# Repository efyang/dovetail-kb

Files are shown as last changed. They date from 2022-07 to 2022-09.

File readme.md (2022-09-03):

# Dovetail Keyboard

Uses a modified version of ergogen that supports placing arbitrary library parts.

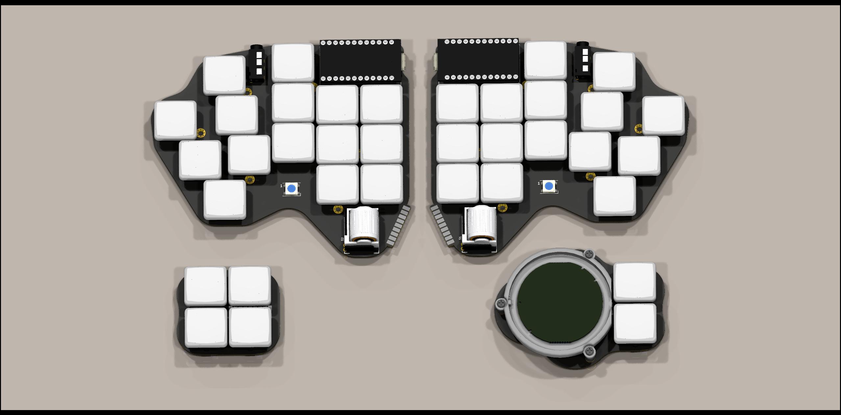
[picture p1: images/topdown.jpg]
Top Down

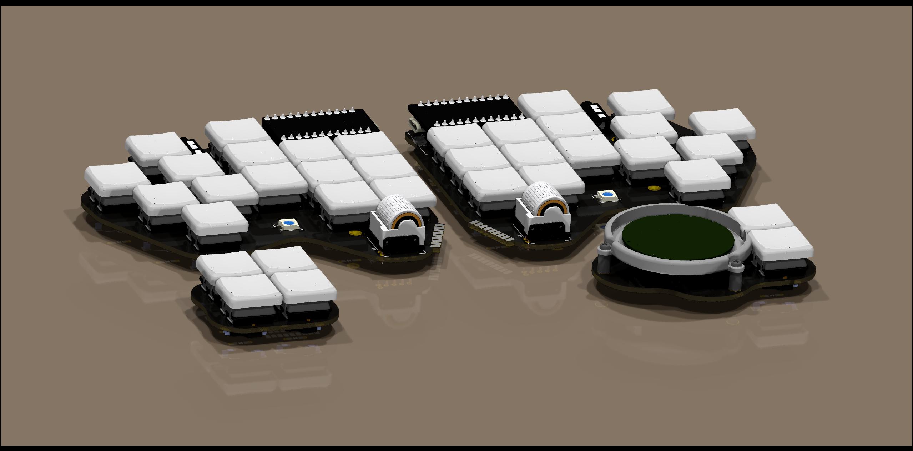
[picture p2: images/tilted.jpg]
Tilted

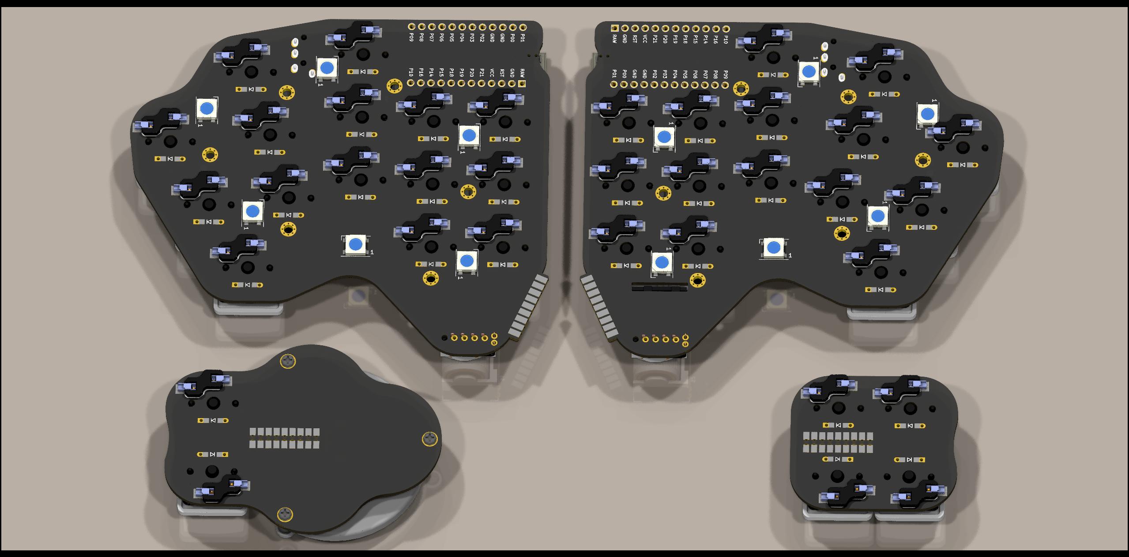
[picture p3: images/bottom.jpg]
Bottom


### FreeCAD Pics (some parts didn't survive the conversion process)

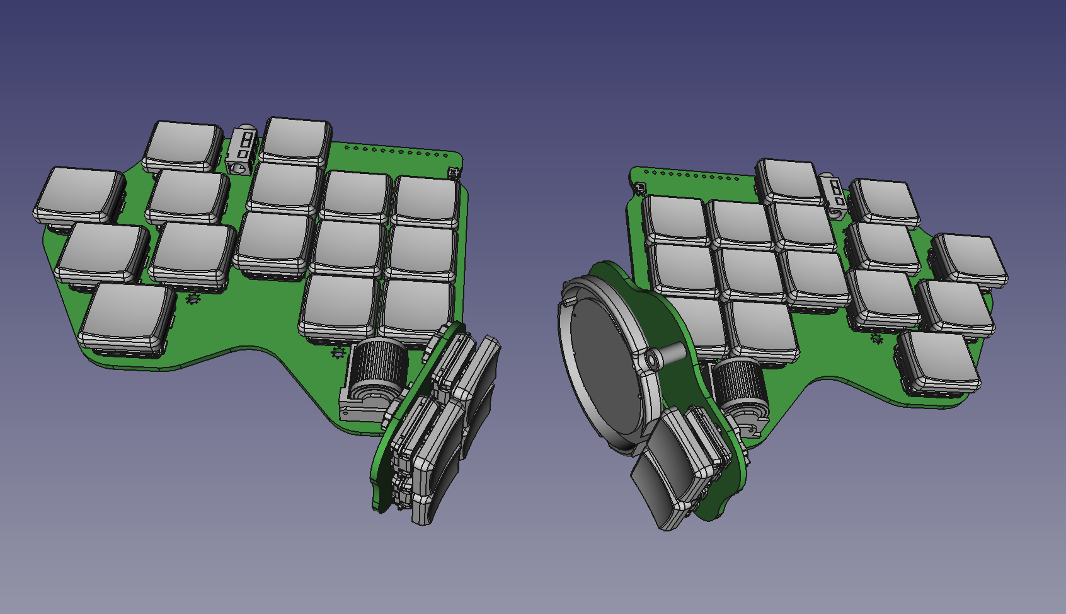
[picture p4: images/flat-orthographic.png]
Flat Orthographic

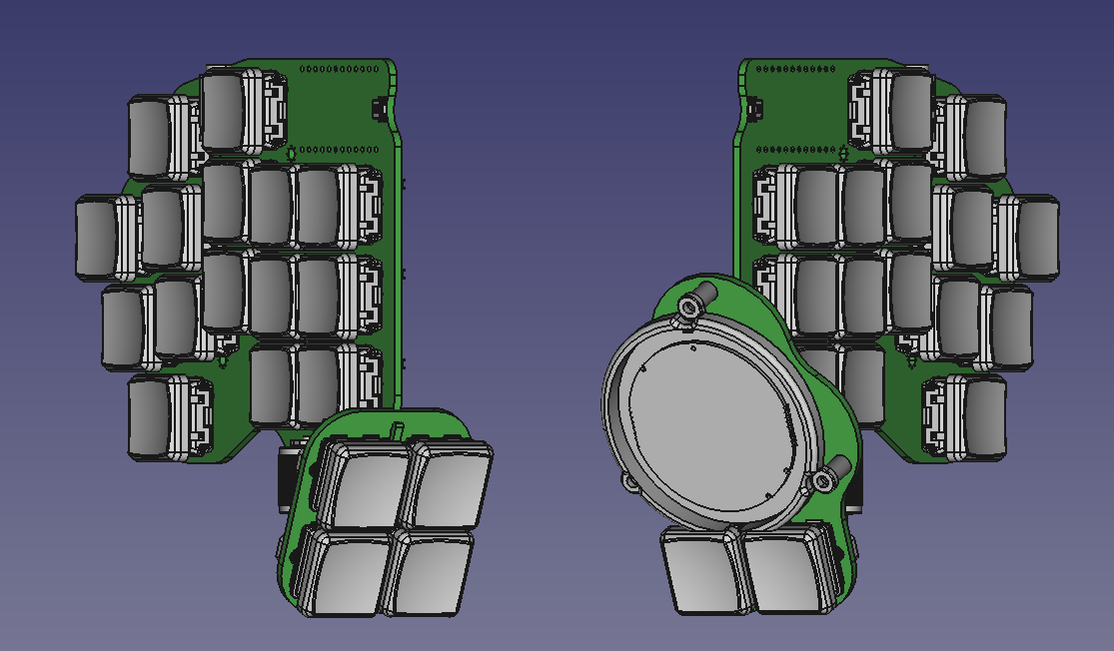
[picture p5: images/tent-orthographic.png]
Tented Orthographic

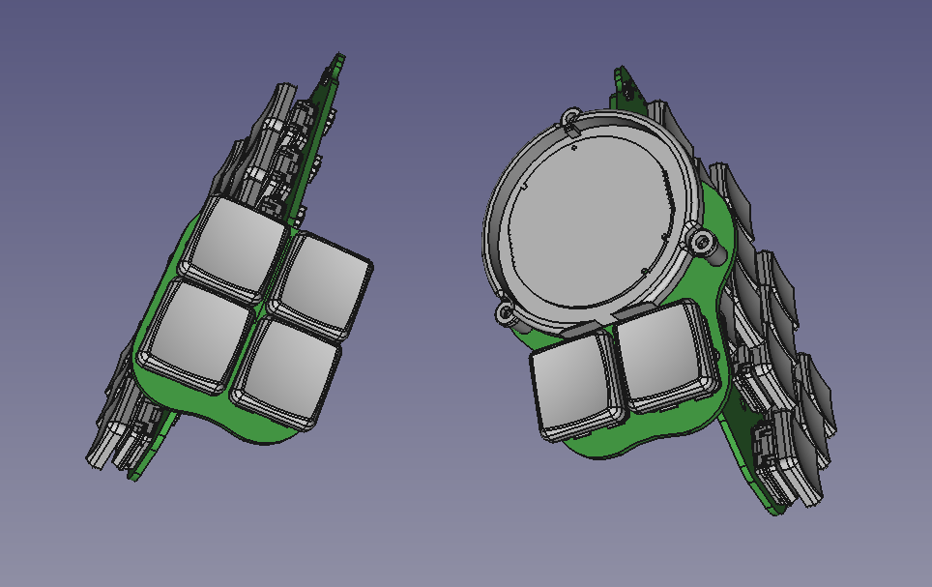
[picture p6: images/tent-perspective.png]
Tented Perspective


## Features

-   underglow
-   trackpad (tm035035-2024-003)
-   solder-on 90-degree thumb clusters
-   choc spacing
-   36 keys

To update using ergogen:

-   `node ergogen/src/cli.js ergogen.yaml -o .`
-   Open pcb in pcbnew
-   Tools -> Update Footprints from Library
-   Check all "Update Options"
-   Update

## Parts list

| Qty | Part | Info | Link(s) | |
| --- | --- | --- | --- | --- |
| 2 | KB2040 | QMK compatible pro-micro footprint. Currently must have QMK for trackpad, recommmended RP2040 | https://www.adafruit.com/product/5302 | |
| 2 | PJ-320A Jack | | https://www.aliexpress.com/item/2251832181971069.html | |
| 36  | Kailh Choc Hotswap Sockets | | https://www.aliexpress.com/item/3256803389452947.html | |
| 3 | M2 Standoffs | Trying M2x7 | https://www.aliexpress.com/item/2251832782516182.html | |
| idk can't count | M2 Screws | | | |
| 1 | FPC Cable | 0.5mm pitch, 12pin, same side (but probably should cut and strip yourself anyways) | https://www.aliexpress.com/item/3256801417741263.html | |
| 1 | FPC Connector | 12P, 0.5mm pitch | https://www.aliexpress.com/item/2261800162045502.html | |
| 4 | MCU Sockets (optional) | I like these ones - PH3.5, use them with regular headers | https://www.aliexpress.com/item/2251832713321083.html | |
| 2 | Scroll Wheel | | https://www.aliexpress.com/item/2251832804635444.html | |
| 14  | WS2812b 5050 | | https://www.aliexpress.com/item/3256802466699315.html | |
| 1 | TM035035-2024-003 Trackpad | Cirque Glide Trackpad with overlay | https://www.mouser.com/ProductDetail/355-TM0350352024-003 | |
| 2 | EVQ-P7C01P Reset Switch | I wanted to be fancy lol | https://www.mouser.com/ProductDetail/667-EVQP7C01P | |
| 1 | Trackpad holder part | Probably want 2 just in case | [In repo](Models/trackpad-holder-Fusion.stl) | |
| 1 | 1 of each PCB minimum | left-main, right-main, left-thumb, right-thumb (you could actually interchange the thumbs) | [In repo](gerbers) | |
| 2 | Plates | Untested | [In repo](outlines/cutout_with_holes.dxf) | |
| 12 | M2 standoffs (5mm) | Untested | https://www.aliexpress.com/item/2251832782591461.html | |
| 2  | 1/4in lock nut | Untested | https://www.aliexpress.com/item/3256802483856268.html | |
| 2  | Camera swivel thingy | Untested | https://www.aliexpress.com/item/3256803400603212.html | |
| 2  | Magnetic Base | Untested | https://www.aliexpress.com/item/3256803496352836.html | |
| 2  | Palm LED Diffuser | Untested | [In repo](outlines/palm_led_diffuser_final.dxf) | |
| 2  | Palm LED Diffuser Spacer | Untested | [In repo](outlines/palm_led_diffuser_spacer.dxf) | |
| 36  | Diodes | | | |
| 1 | Case (optional) | | https://www.aliexpress.com/item/3256803532895347.html | |

## Notes

-   Designed for 3.3v power/logic (kb2040)
    -   if you want to use 5v then you have to desolder more on the trackpad pcb
-   Rectangular size (at most): ~ 14cmx11cmx5.5cm

## Inspo/Useful Links
- https://www.reddit.com/r/ErgoMechKeyboards/comments/uq2yyq/kyria_with_cirque_circle_trackpad/
- https://github.com/macroxue/keyboard-tenting
- https://www.reddit.com/r/PeripheralDesign/comments/uk9l94/trackball_emulation_on_cirque_glidepoint_circle/
- https://www.cirque.com/message-board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
- https://github.com/dkao/qmk_firmware/commits/cirque_trackpad_features
- https://www.thingiverse.com/thing:5385829/files
- https://github.com/Bastardkb/dilemma

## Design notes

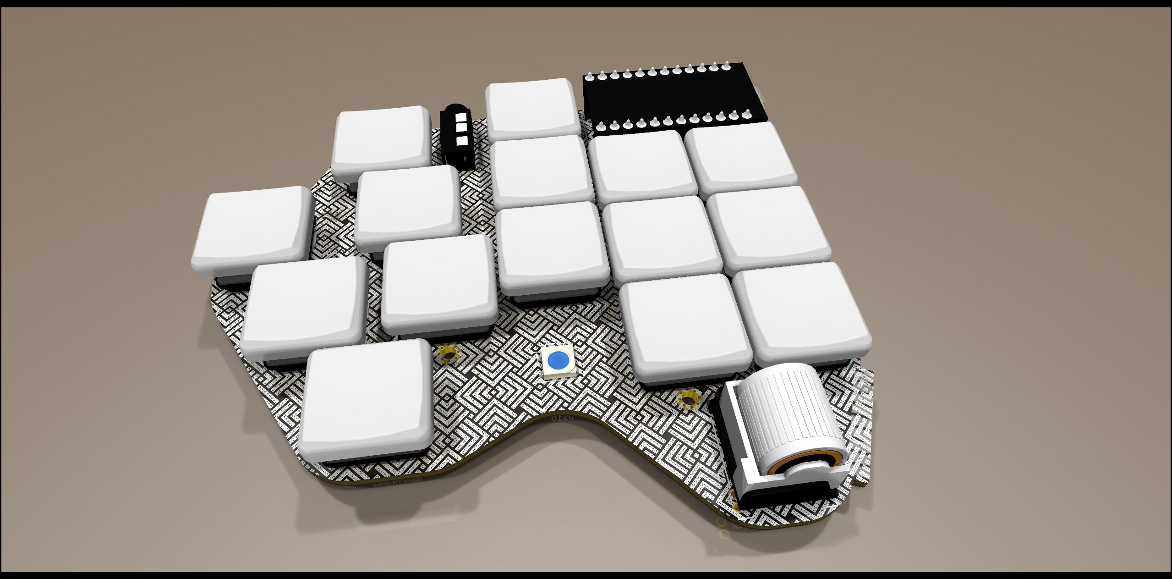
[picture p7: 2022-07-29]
images/patterned.jpg

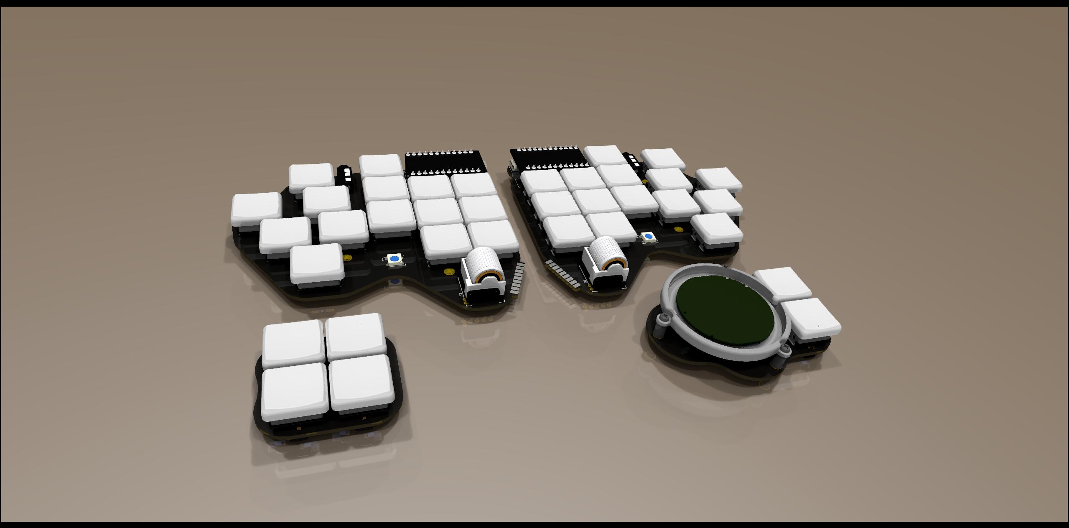
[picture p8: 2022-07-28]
images/tilted2.jpg

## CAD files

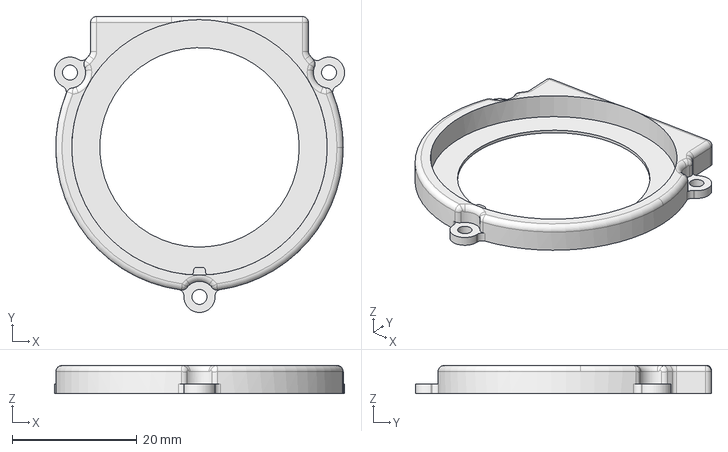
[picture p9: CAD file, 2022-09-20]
Models/trackpad-holder.FCStd
46.6 x 47.5 x 4.50 mm

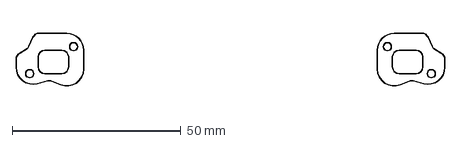
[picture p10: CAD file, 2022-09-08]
outlines/palm_led_diffuser_spacer.dxf
127.0 x 15.9 mm

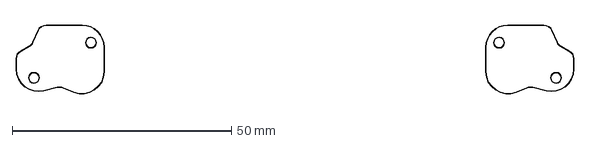
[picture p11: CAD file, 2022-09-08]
outlines/palm_led_diffuser_final.dxf
127.0 x 15.9 mm

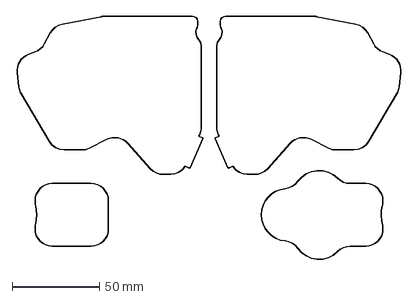
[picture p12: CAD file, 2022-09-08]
outlines/cutout_final.dxf
220.3 x 139.3 mm

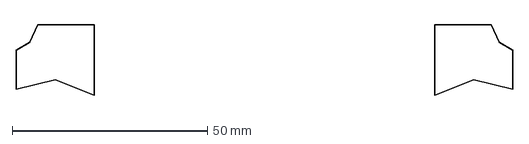
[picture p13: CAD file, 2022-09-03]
outlines/palm_led_diffuser_outline.dxf
127.0 x 18.0 mm

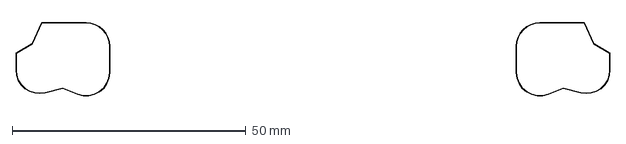
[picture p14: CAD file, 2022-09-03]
outlines/palm_led_diffuser_stage0.dxf
127.0 x 15.9 mm

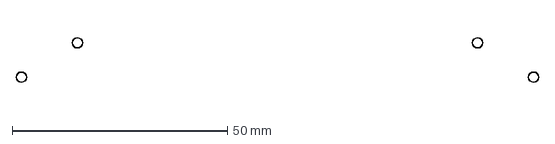
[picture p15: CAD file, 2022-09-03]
outlines/palm_led_diffuser_holes.dxf
121.4 x 10.4 mm

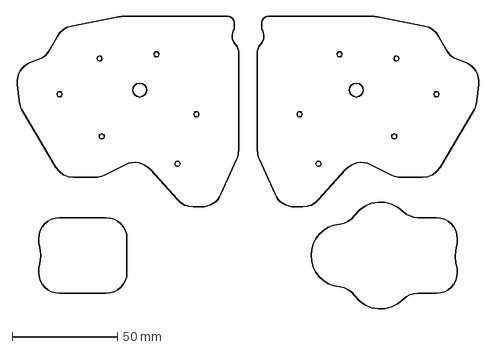
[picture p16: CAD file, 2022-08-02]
outlines/cutout_with_holes.dxf
220.3 x 139.3 mm

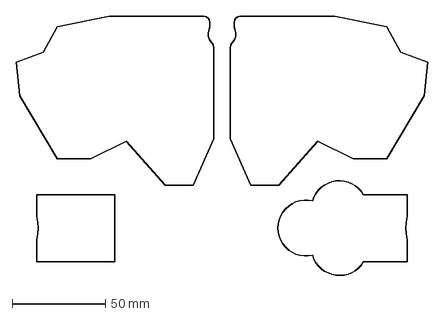
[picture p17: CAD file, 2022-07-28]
outlines/cutout_all.dxf
221.0 x 139.6 mm

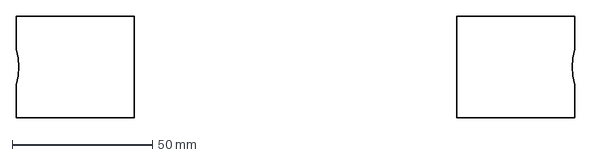
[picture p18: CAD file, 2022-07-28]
outlines/thumbrect_stage1.dxf
199.0 x 36.0 mm

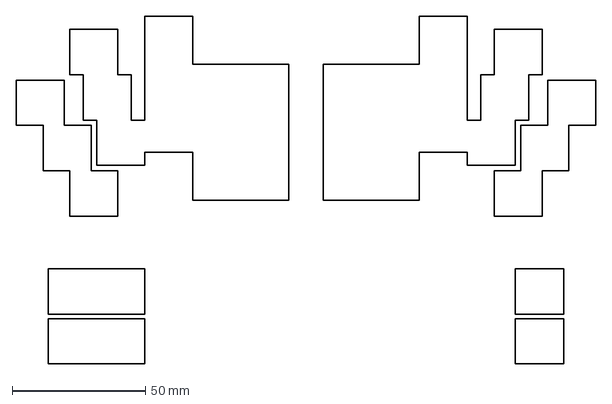
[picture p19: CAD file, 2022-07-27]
outlines/raw.dxf
217.0 x 130.4 mm

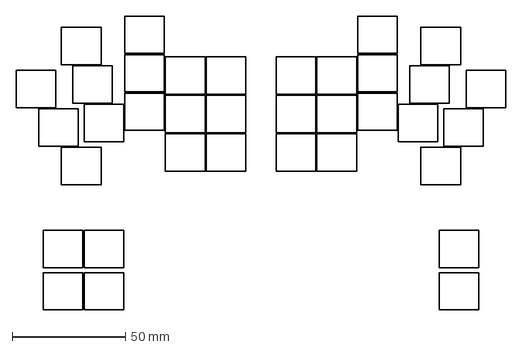
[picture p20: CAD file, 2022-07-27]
outlines/keycap_outlines.dxf
216.5 x 129.9 mm

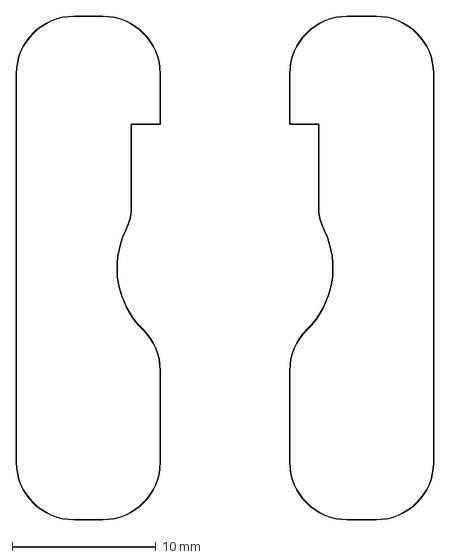
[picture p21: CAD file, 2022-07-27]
outlines/reset_nub_smooth1.dxf
29.0 x 35.0 mm

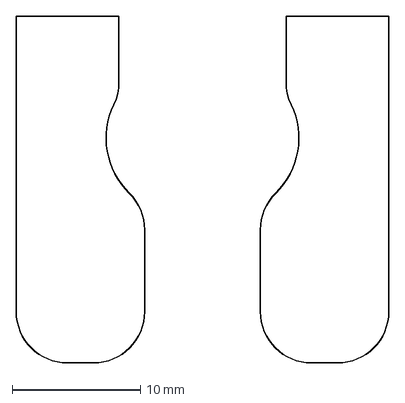
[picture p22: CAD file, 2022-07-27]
outlines/reset_nub.dxf
29.0 x 27.0 mm

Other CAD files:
Models/trackpad-holder-Fusion.step
outlines/reset_nub_stage1.dxf
Models/trackpad-holder-Fusion.stl

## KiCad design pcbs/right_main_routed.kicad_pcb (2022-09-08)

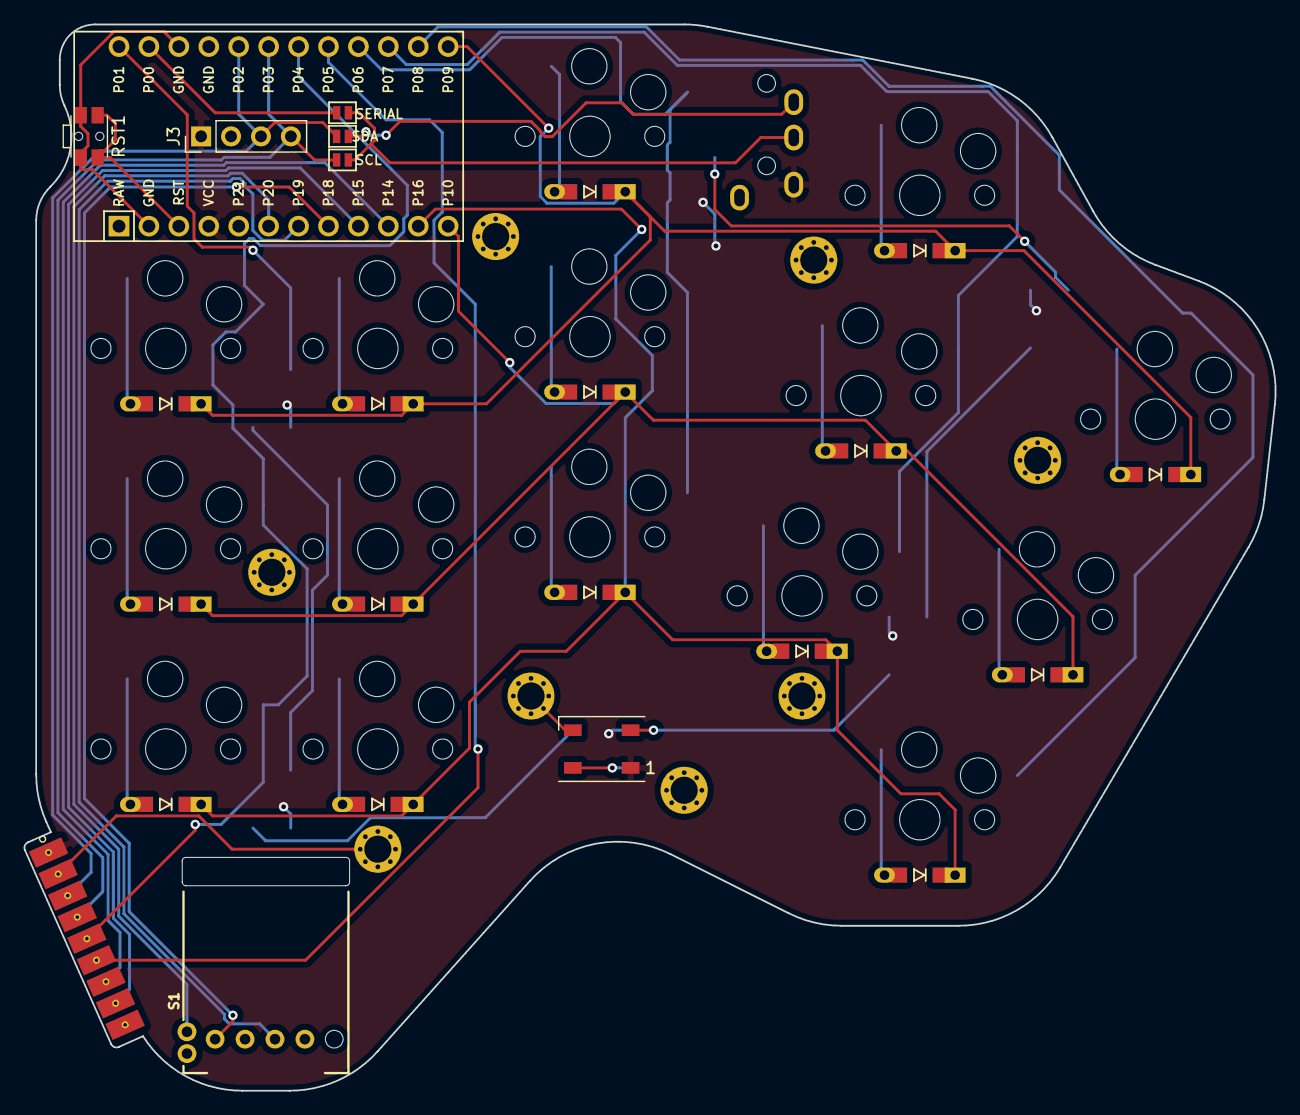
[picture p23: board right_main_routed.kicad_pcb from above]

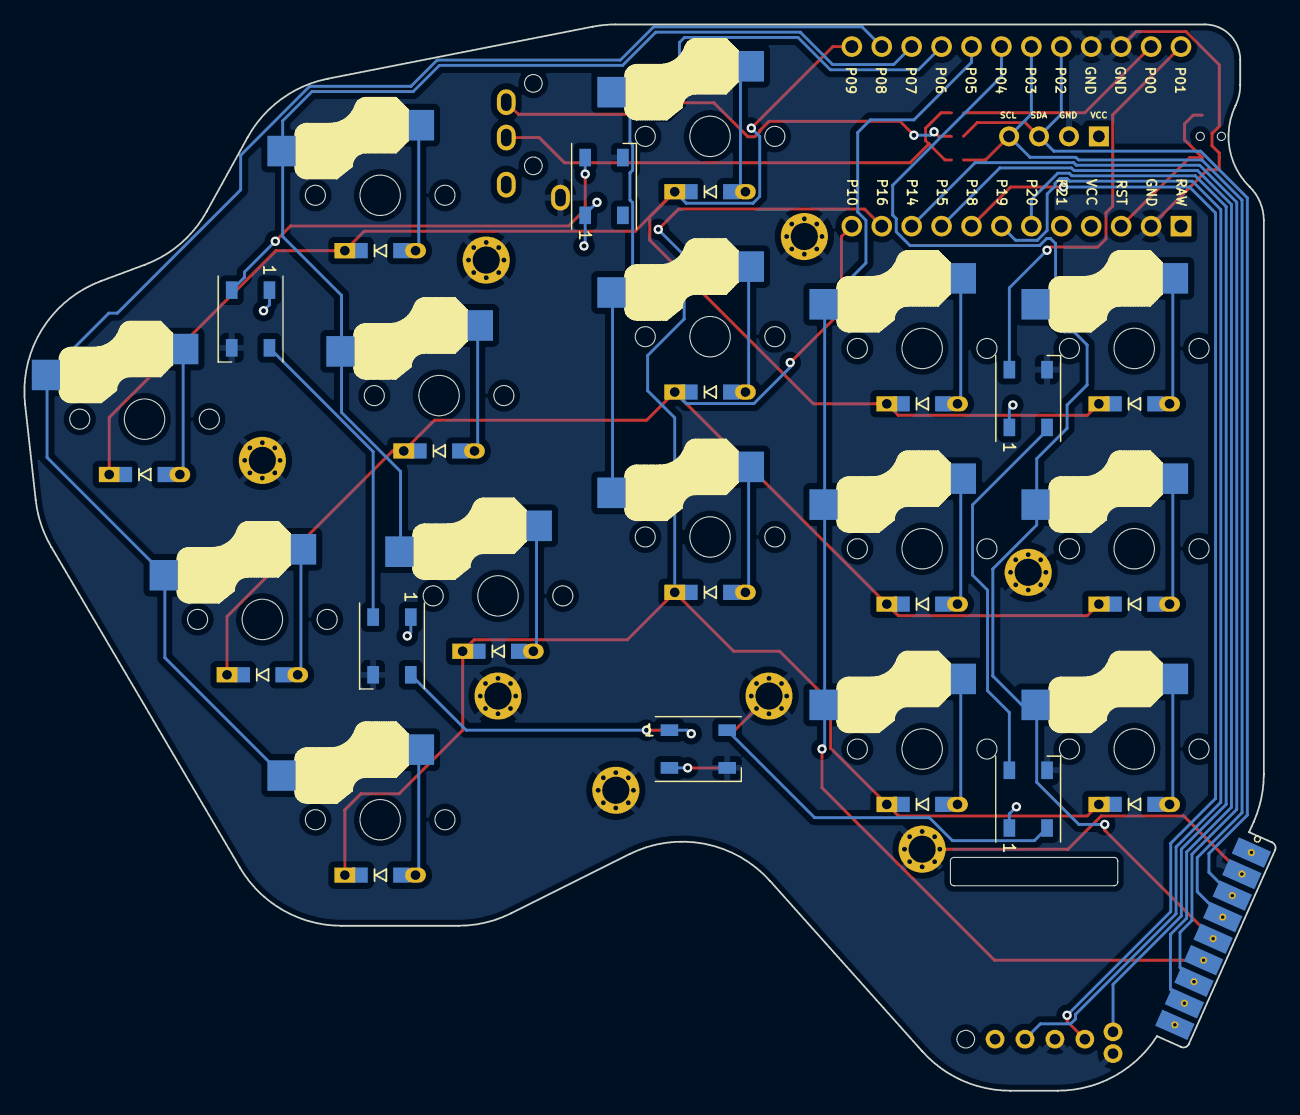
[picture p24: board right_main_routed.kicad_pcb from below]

Board: 2 copper layers, 106.2 x 90.5 mm, 54 parts (6 on the bottom side), 43 nets.

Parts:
D1, D2, D3, D4, D5, D6, D7, D8, D9, D10, D11, D12, D13, D14, D15: Diode; D3_TH_SMD_v2
DS1, DS2, DS3, DS4, DS5, DS6, DS7: WS2812b; LED_WS2812B_PLCC4_5.0x5.0mm_P3.2mm
H1, H3, H5, H7, H9, H11, H13, H15: M2; M2_HOLE_v3
J1: TRRS; TRRS-PJ-320A
J3: I2C Breakout; PinHeader_1x04_P2.54mm_Vertical
J5: SERIAL; Jumper
J6: SDA; Jumper
J7: SCL; Jumper
J14: Male 9pin; kb_90deg_connector_male_9pin
RST1: RST; SW_SPST_EVQP7C
S1: Scroll Wheel; EVQWGD001
SW1, SW2, SW3, SW4, SW5, SW6, SW7, SW8, SW9, SW10, SW11, SW12, SW13, SW14, SW15: Val**; PG1350
U1: Pro Micro Footprint; ProMicro

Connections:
C1: J14.5, SW1.2, SW2.2, SW3.2, U1.19
C2: J14.6, SW4.2, SW5.2, SW6.2, U1.20
C3: SW7.2, SW8.2, SW9.2, U1.21
C4: SW10.2, SW11.2, SW12.2, U1.22
C5: SW13.2, SW14.2, SW15.2, U1.23
GND: DS1.3, DS2.3, DS3.3, DS4.3, DS5.3, DS6.3, DS7.3, H1.1, H3.1, H5.1, H7.1, H9.1, H11.1, H13.1, H15.1, J1.1, J3.2, J14.2, RST1.2, S1.B, S1.S1, U1.2, U1.15, U1.16
R1: D3.1, D6.1, D9.1, D12.1, D15.1, U1.24
R2: D2.1, D5.1, D8.1, D11.1, D14.1, U1.12
R3: D1.1, D4.1, D7.1, D10.1, D13.1, U1.11
R4: J14.7, U1.10
R5: J14.8, U1.9
RGB: DS1.4, U1.13
RST: RST1.1, U1.3
SCL: J3.4, J7.1, J14.4, U1.18
SDA: J3.3, J6.1, J14.3, U1.17
SERIAL: J5.1, U1.14
TRRS3: J1.3, J5.2, J7.2
TRRS4: J1.4, J6.2
VCC: DS1.1, DS2.1, DS3.1, DS4.1, DS5.1, DS6.1, DS7.1, J1.2, J3.1, J14.1, U1.4
far_bottom: D1.2, SW1.1
far_home: D2.2, SW2.1
far_top: D3.2, SW3.1
index_bottom: D4.2, SW4.1
index_home: D5.2, SW5.1
index_top: D6.2, SW6.1
middle_bottom: D7.2, SW7.1
middle_home: D8.2, SW8.1
middle_top: D9.2, SW9.1
pinkie_bottom: D13.2, SW13.1
pinkie_home: D14.2, SW14.1
pinkie_top: D15.2, SW15.1
rgb_palm_out: DS4.2, DS5.4
rgb_ug1_out: DS1.2, DS2.4
rgb_ug2_out: DS2.2, DS3.4
rgb_ug3_out: DS3.2, DS4.4
rgb_ug4_out: DS5.2, DS6.4
rgb_ug5_out: DS6.2, DS7.4
ring_bottom: D10.2, SW10.1
ring_home: D11.2, SW11.1
ring_top: D12.2, SW12.1
scroll_r1: S1.A, U1.8
scroll_r2: S1.C, U1.7
scroll_switch: S1.S2, U1.6

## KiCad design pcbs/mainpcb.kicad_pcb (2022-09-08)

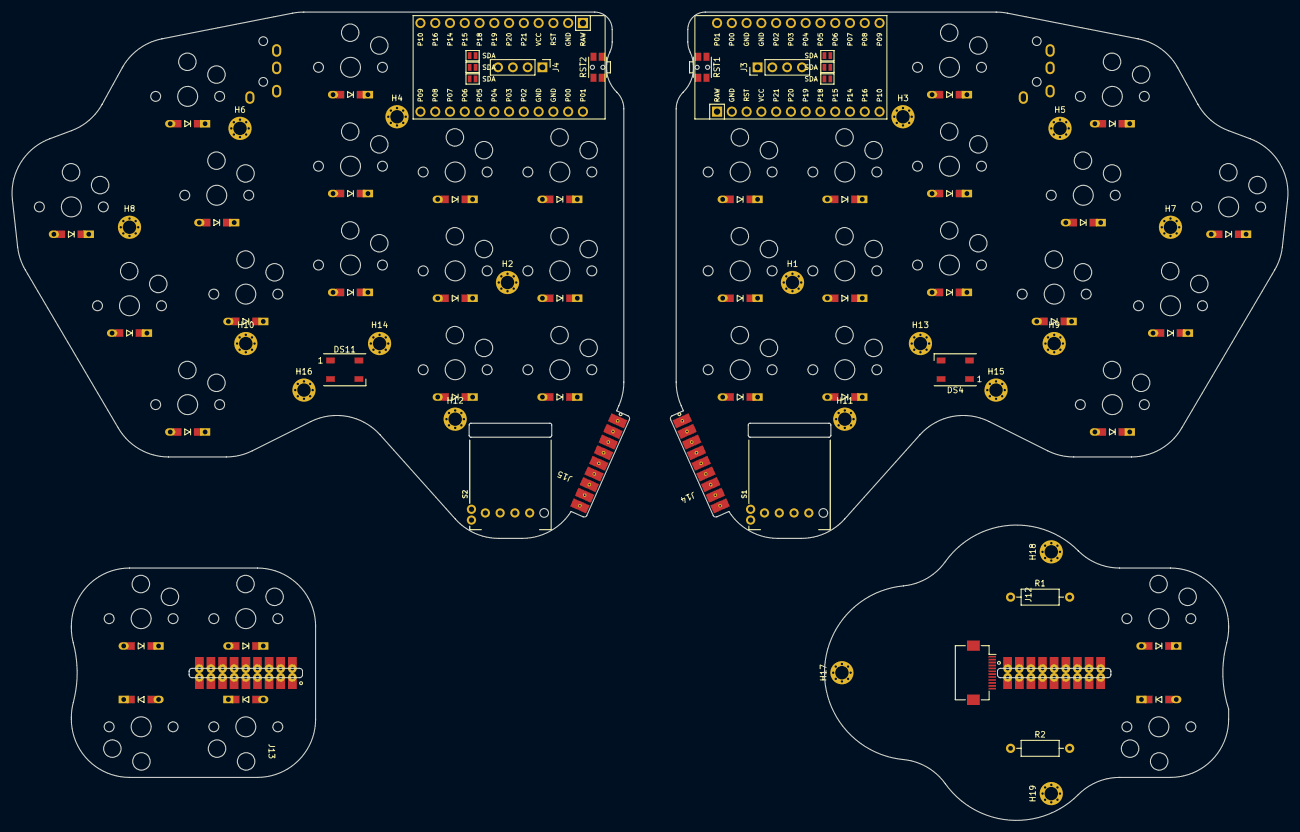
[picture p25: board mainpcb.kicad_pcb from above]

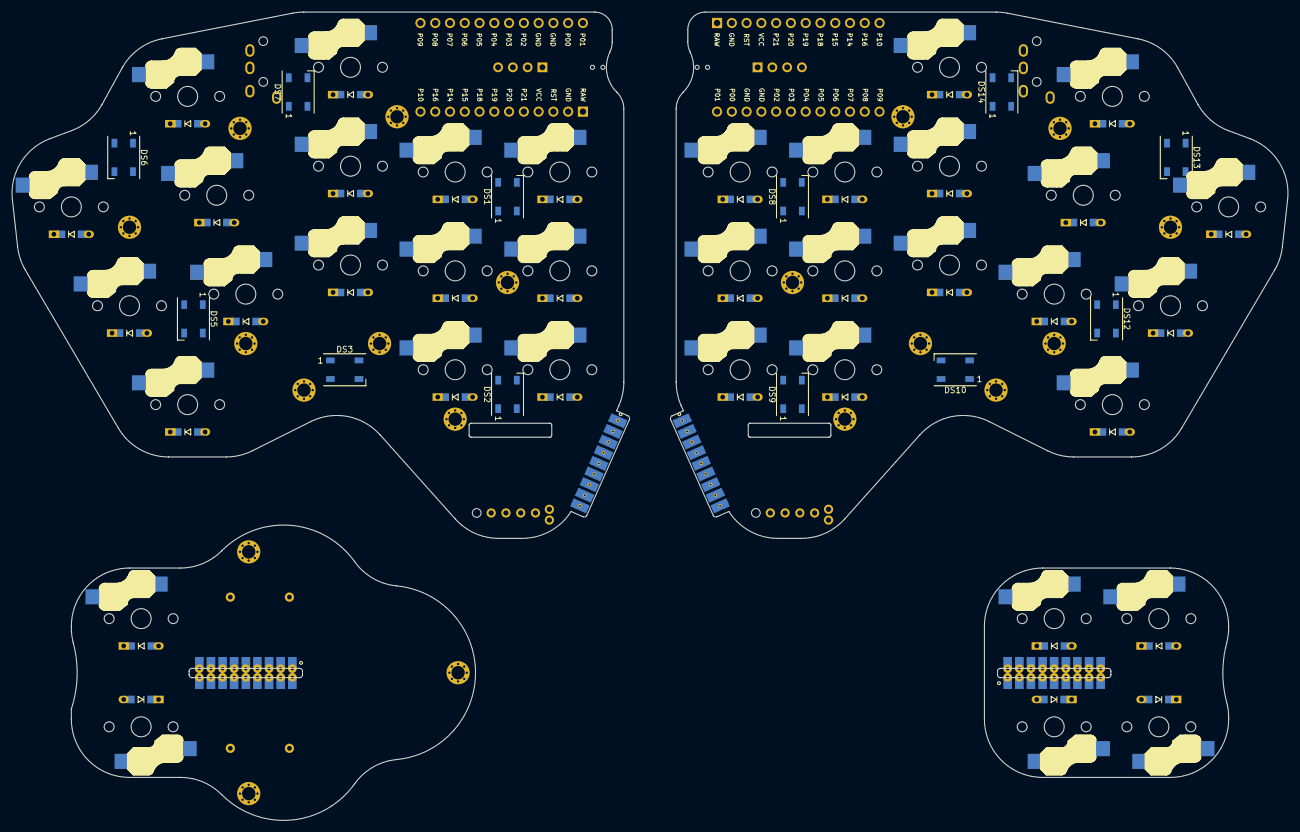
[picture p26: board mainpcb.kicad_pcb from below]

Board: 2 copper layers, 219.4 x 139.0 mm, 128 parts (12 on the bottom side), 65 nets, no tracks yet.

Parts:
D1, D2, D3, D4, D5, D6, D7, D8, D9, D10, D11, D12, D13, D14, D15, D16, D17, D18, D19, D20, D21, D22, D23, D24, D25, D26, D27, D28, D29, D30, D31, D32, D33, D34, D35, D36: Diode; D3_TH_SMD_v2
DS1, DS2, DS3, DS4, DS5, DS6, DS7, DS8, DS9, DS10, DS11, DS12, DS13, DS14: WS2812b; LED_WS2812B_PLCC4_5.0x5.0mm_P3.2mm
H1, H2, H3, H4, H5, H6, H7, H8, H9, H10, H11, H12, H13, H14, H15, H16, H17, H18, H19: M2; M2_HOLE_v3
J1, J2: TRRS; TRRS-PJ-320A
J3, J4: I2C Breakout; PinHeader_1x04_P2.54mm_Vertical
J5, J6, J7, J8, J9, J10: SDA; Jumper
J11: 12pin FPC; Hirose_FH12-12S-0.5SH_1x12-1MP_P0.50mm_Horizontal
J12, J13: Female 9pin; kb_90deg_connector_female_9pin
J14, J15: Male 9pin; kb_90deg_connector_male_9pin
R1, R2: 4K7; R_Axial_DIN0207_L6.3mm_D2.5mm_P10.16mm_Horizontal
RST1, RST2: RST; SW_SPST_EVQP7C
S1, S2: Scroll Wheel; EVQWGD001
SW1, SW2, SW3, SW4, SW5, SW6, SW7, SW8, SW9, SW10, SW11, SW12, SW13, SW14, SW15, SW16, SW17, SW18, SW19, SW20, SW21, SW22, SW23, SW24, SW25, SW26, SW27, SW28, SW29, SW30, SW31, SW32, SW33, SW34, SW35, SW36: Val**; PG1350
U1, U2: Pro Micro Footprint; ProMicro

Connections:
C1: J12.5, J13.5, J14.5, J15.5, SW1.2, SW2.2, SW3.2, SW16.2, SW18.2, SW19.2, SW20.2, SW33.2, SW34.2, U1.19, U2.19
C2: J12.6, J13.6, J14.6, J15.6, SW4.2, SW5.2, SW6.2, SW17.2, SW21.2, SW22.2, SW23.2, SW35.2, SW36.2, U1.20, U2.20
C3: SW7.2, SW8.2, SW9.2, SW24.2, SW25.2, SW26.2, U1.21, U2.21
C4: SW10.2, SW11.2, SW12.2, SW27.2, SW28.2, SW29.2, U1.22, U2.22
C5: SW13.2, SW14.2, SW15.2, SW30.2, SW31.2, SW32.2, U1.23, U2.23
GND: DS1.3, DS2.3, DS3.3, DS4.3, DS5.3, DS6.3, DS7.3, DS8.3, DS9.3, DS10.3, DS11.3, DS12.3, DS13.3, DS14.3, H1.1, H2.1, H3.1, H4.1, H5.1, H6.1, H7.1, H8.1, H9.1, H10.1, H11.1, H12.1, H13.1, H14.1, H15.1, H16.1, H17.1, H18.1, H19.1, J1.1, J2.1, J3.2, J4.2, J11.2, J12.2, J13.2, J14.2, J15.2, RST1.2, RST2.2, S1.B, S1.S1, S2.B, S2.S1, U1.2, U1.15, U1.16, U2.2, U2.15, U2.16
R1: D3.1, D6.1, D9.1, D12.1, D15.1, D20.1, D23.1, D26.1, D29.1, D32.1, U1.24, U2.24
R2: D2.1, D5.1, D8.1, D11.1, D14.1, D19.1, D22.1, D25.1, D28.1, D31.1, U1.12, U2.12
R3: D1.1, D4.1, D7.1, D10.1, D13.1, D18.1, D21.1, D24.1, D27.1, D30.1, U1.11, U2.11
R4: D16.1, D17.1, D33.1, D35.1, J12.7, J13.7, J14.7, J15.7, U1.10, U2.10
R5: D34.1, D36.1, J12.8, J13.8, J14.8, J15.8, U1.9, U2.9
RGB: DS1.4, DS8.4, U1.13, U2.13
RST: RST1.1, RST2.1, U1.3, U2.3
SCL: J3.4, J4.4, J7.1, J10.1, J11.4, J12.4, J13.4, J14.4, J15.4, R2.2, U1.18, U2.18
SDA: J3.3, J4.3, J6.1, J9.1, J11.3, J12.3, J13.3, J14.3, J15.3, R1.2, U1.17, U2.17
SERIAL: J5.1, J8.1, U1.14, U2.14
TRRS3: J1.3, J2.3, J5.2, J7.2, J8.2, J10.2
TRRS4: J1.4, J2.4, J6.2, J9.2
VCC: DS1.1, DS2.1, DS3.1, DS4.1, DS5.1, DS6.1, DS7.1, DS8.1, DS9.1, DS10.1, DS11.1, DS12.1, DS13.1, DS14.1, J1.2, J2.2, J3.1, J4.1, J11.1, J12.1, J13.1, J14.1, J15.1, R1.1, R2.1, U1.4, U2.4
c1_r4: D16.2, SW16.1
c2_r4: D17.2, SW17.1
far_bottom: D1.2, SW1.1
far_home: D2.2, SW2.1
far_top: D3.2, SW3.1
index_bottom: D4.2, SW4.1
index_home: D5.2, SW5.1
index_top: D6.2, SW6.1
middle_bottom: D7.2, SW7.1
middle_home: D8.2, SW8.1
middle_top: D9.2, SW9.1
mirror_c1_r4: D33.2, SW33.1
mirror_c1_r5: D34.2, SW34.1
mirror_c2_r4: D35.2, SW35.1
mirror_c2_r5: D36.2, SW36.1
mirror_far_bottom: D18.2, SW18.1
mirror_far_home: D19.2, SW19.1
mirror_far_top: D20.2, SW20.1
mirror_index_bottom: D21.2, SW21.1
mirror_index_home: D22.2, SW22.1
mirror_index_top: D23.2, SW23.1
mirror_middle_bottom: D24.2, SW24.1
mirror_middle_home: D25.2, SW25.1
mirror_middle_top: D26.2, SW26.1
mirror_pinkie_bottom: D30.2, SW30.1
mirror_pinkie_home: D31.2, SW31.1
mirror_pinkie_top: D32.2, SW32.1
mirror_ring_bottom: D27.2, SW27.1
mirror_ring_home: D28.2, SW28.1
mirror_ring_top: D29.2, SW29.1
pinkie_bottom: D13.2, SW13.1
pinkie_home: D14.2, SW14.1
pinkie_top: D15.2, SW15.1
rgb_palm_out: DS4.2, DS5.4, DS11.2, DS12.4
rgb_ug1_out: DS1.2, DS2.4, DS8.2, DS9.4
rgb_ug2_out: DS2.2, DS3.4, DS9.2, DS10.4
rgb_ug3_out: DS3.2, DS4.4, DS10.2, DS11.4
rgb_ug4_out: DS5.2, DS6.4, DS12.2, DS13.4
rgb_ug5_out: DS6.2, DS7.4, DS13.2, DS14.4
rgb_ug6_out: DS7.2, DS14.2
ring_bottom: D10.2, SW10.1
ring_home: D11.2, SW11.1
ring_top: D12.2, SW12.1
scroll_r1: S1.A, S2.A, U1.8, U2.8
scroll_r2: S1.C, S2.C, U1.7, U2.7
scroll_switch: S1.S2, S2.S2, U1.6, U2.6

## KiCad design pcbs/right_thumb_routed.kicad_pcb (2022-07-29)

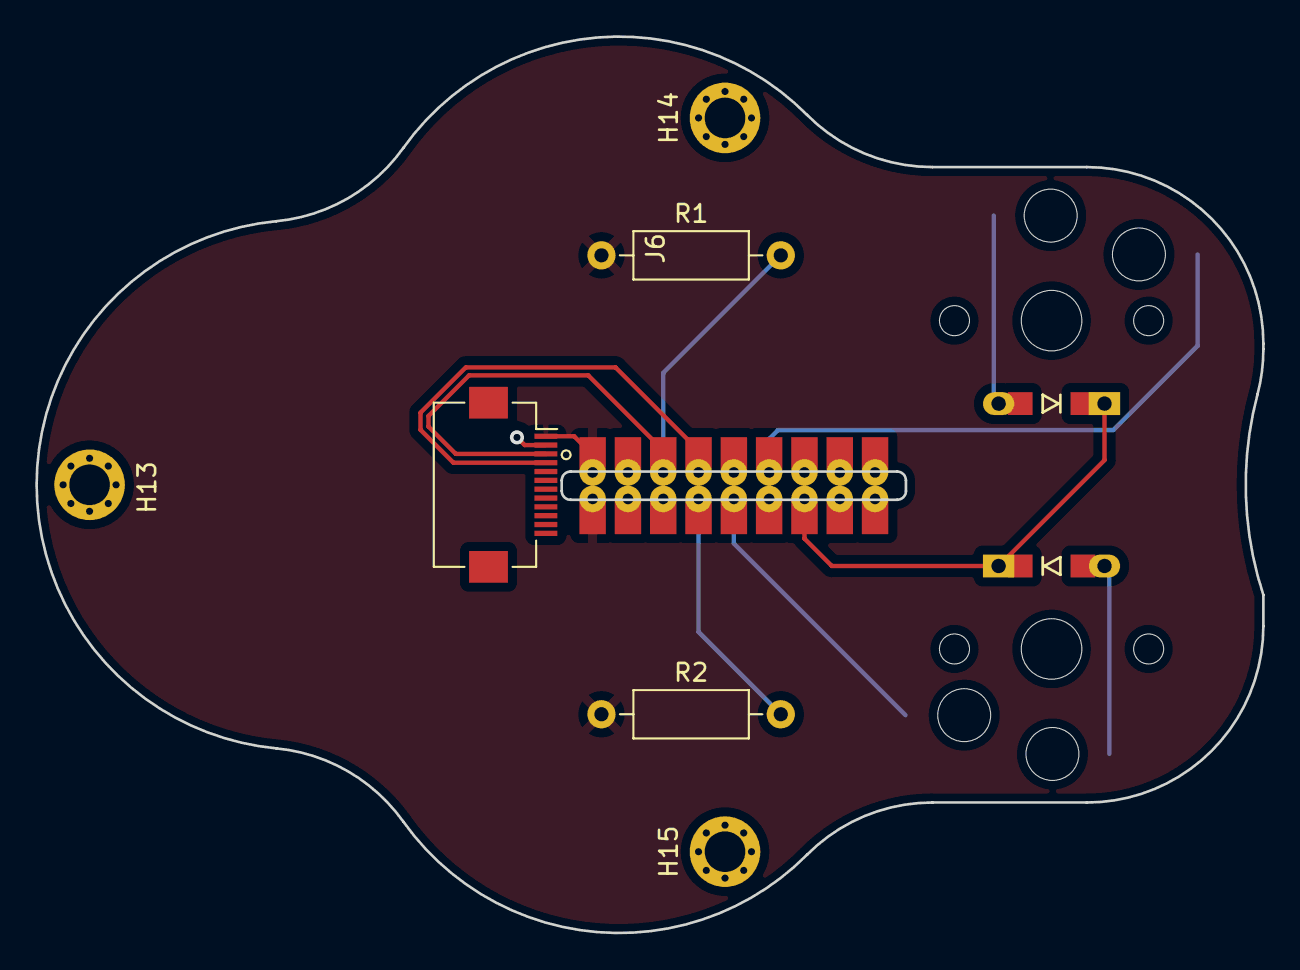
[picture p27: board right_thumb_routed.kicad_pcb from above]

Board: 2 copper layers, 69.5 x 50.8 mm, 11 parts (0 on the bottom side), 9 nets.

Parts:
D16, D17: Diode; D3_TH_SMD_v2
H13, H14, H15: M2; M2_HOLE_v3
J5: 12pin FPC; Hirose_FH12-12S-0.5SH_1x12-1MP_P0.50mm_Horizontal
J6: Female 9pin; kb_90deg_connector_female_9pin
R1, R2: 4K7; R_Axial_DIN0207_L6.3mm_D2.5mm_P10.16mm_Horizontal
SW16, SW17: Val**; PG1350

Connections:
C1: J6.5, SW16.2
C2: J6.6, SW17.2
GND: H13.1, H14.1, H15.1, J5.2, J6.2
R4: D16.1, D17.1, J6.7
SCL: J5.4, J6.4, R2.2
SDA: J5.3, J6.3, R1.2
VCC: J5.1, J6.1, R1.1, R2.1
c1_r4: D16.2, SW16.1
c2_r4: D17.2, SW17.1

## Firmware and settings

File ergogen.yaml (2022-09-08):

units:
  trackpad_size: 54
  trackpad_shift: -5
  pcb_thickness: 1.6
  conn_rot: atan2((-cx/2 - 2), -(cy/2 + cy+3.5) - -cy/4)
  trackpad_center_shift_x: cy/2+pcb_thickness/2
  trackpad_center_shift_y: trackpad_size/2 + cy/2 + trackpad_shift
  trackpad_screw_offset_radius: 24
  promicro_center_shift_x: -36/2 - cx/2 + 1
  promicro_center_shift_y: 0
  connector_length: 19
  m2_clearance_radius: 2.4/2
  i1_4_clearance_radius: 6.6/2

points:
  key:
    padding: cy
    footprints:
      choc_hotswap:
        $extends: footprints.choc_hotswap
        nets:
          2: =column_net
          1: =colrow
      diode:
        $extends: footprints.combo_diode
        nets:
          2: =colrow #from
          1: =row_net #to
        anchor:
          rotate: 180
          shift: [0, -4.7]

  zones:
    main:
      rows:
        bottom:
          row_net: R3
        home:
          row_net: R2
        top:
          row_net: R1
      columns:
        far:
          spread: cx
          key:
            column_net: C1
        index:
          spread: cx
          key:
            column_net: C2
        middle:
          spread: cx
          stagger: 18
          key:
            column_net: C3
        ring:
          key:
            column_net: C4
          stagger: -5
          spread: 23
          origin: [0, cy]
          rows:
            bottom:
              shift: [cx-23, 0]
            top:
              shift: [23-cx, 0]
        pinkie:
          key:
            column_net: C5
          spread: 15
          stagger: -19
          origin: [0, cy]
          rows:
            bottom:
              shift: [-10, 0]
            top:
              shift: [10, 0]
    thumb:
      anchor:
        orient: 90
        shift: [-80, -90]
      rows:
        r4:
          padding: cx
          row_net: R4
        r5:
          asym: right
          padding: cx
          row_net: R5
      columns:
        c1:
          spread: cy+pcb_thickness
          key:
            column_net: C1
            origin: [0, 0]
            rotate: 90
        c2:
          spread: cy+pcb_thickness
          key:
            column_net: C2
            origin: [0, 0]
            rotate: -90
  mirror:
    distance: 5

outlines:
  exports:
    raw:
      - type: keys
        side: both
        size: [1cx , 1cy]
    keycap_outlines:
      - type: keys
        side: both
        size: [1cx - 0.5, 1cy - 0.5] # Choc keycaps are 17.5 x 16.5
        bound: false
    reset_nub_stage1:
      - type: rectangle
        mirror: true
        size: [10, 35]
        anchor:
          ref: main_middle_top
          shift: [-cx/2 - 36 - 2,-35/2]
      - operation: subtract
        type: circle
        mirror: true
        radius: 6
        anchor:
          ref: main_middle_top
          shift: [-cx/2 - 36 - 5,0]
      - operation: subtract
        type: rectangle
        mirror: true
        size: [10, 10]
        anchor:
          ref: main_middle_top
          shift: [-cx/2 - 36 - 10, 0]

    reset_nub_smooth1:
      - type: outline
        name: reset_nub_stage1
        fillet: 4
    reset_nub_stage2:
      - type: outline
        name: reset_nub_smooth1
      - operation: subtract
        type: rectangle
        mirror: true
        size: [10, 10]
        anchor:
          ref: main_middle_top
          shift: [-cx/2 - 36 - 2,(cy)/2+1]
    reset_nub:
      - type: outline
        name: reset_nub_stage2
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

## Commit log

2022-07-27 Version 1 layout?
    [custom-keyboard.kicad_pcb, custom-keyboard.kicad_sch, cutout_all.dxf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]
2022-07-28 I can't believe I learned freecad for this + mounting holes
    [cutout_all.dxf, cutout_final.dxf, cutout_polies.dxf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]
2022-07-28 Hopefully finalized layout + more pretty pics and cad
    [cutout_all.dxf, cutout_final.dxf, cutout_polies.dxf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]
2022-07-28 Add resistors
    [mainpcb.kicad_pcb]
2022-07-28 Finish fillets
    [trackpad-holder-Fusion.step, trackpad-holder-Fusion.stl, trackpad-holder.FCStd]
2022-07-29 Finish v1 with gerbers?
    [left_main_routed-B_Cu.gbr, left_main_routed-B_Mask.gbr, left_main_routed-B_Paste.gbr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]
2022-08-02 Add plate generator
    [cutout_with_holes.dxf, mainpcb.kicad_pcb]
2022-09-03 Add palm led diffuser
    [mainpcb.kicad_pcb, palm_led_diffuser_final.dxf, palm_led_diffuser_holes.dxf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]
2022-09-20 Update trackpad holder
    [trackpad-holder-Fusion.step, trackpad-holder-Fusion.stl, trackpad-holder.FCStd]
